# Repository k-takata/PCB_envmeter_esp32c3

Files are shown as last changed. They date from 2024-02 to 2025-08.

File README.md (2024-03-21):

# IoT環境メーター / スマートリモコン

## 概要

ESP32-C3とBoschのBME680を使い、温度、湿度、気圧、二酸化炭素換算値などを測定し、結果を[Ambient](https://ambidata.io/)にアップロードできる環境メーターです。  
表示には0.96inch OLEDを使用し、スイッチで通常表示・詳細表示・簡易表示を切り替えることができます。  
Rev. 2 からは赤外線送受信部を備え、スマートリモコン機能も使うことができます。

Rev. 1 のソフトウェア及び解説記事は「[ESP32-C3とBME680でIoT環境メーターを作る](https://zenn.dev/k_takata/articles/esp32c3-envmeter)」で公開しています。  
Rev. 2 のソフトウェア及び解説記事は以下で公開しています。

* [ESP32-C3とBME680でIoT環境メーター/スマートリモコンを作る (その1)](https://zenn.dev/k_takata/articles/esp32c3-envmeter-rev2-1)
* [ESP32-C3とBME680でIoT環境メーター/スマートリモコンを作る (その2)](https://zenn.dev/k_takata/articles/esp32c3-envmeter-rev2-2)

## 使用したソフトウェア

KiCad 7.0

## 回路図

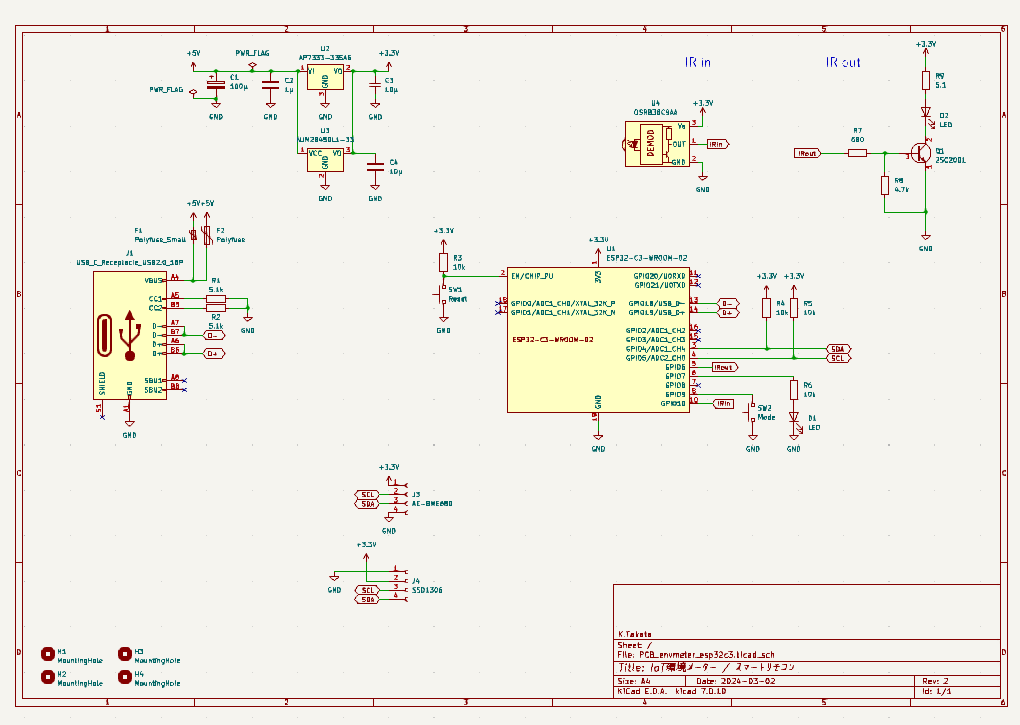
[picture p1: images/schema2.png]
schema rev.2


## 基板パターン図

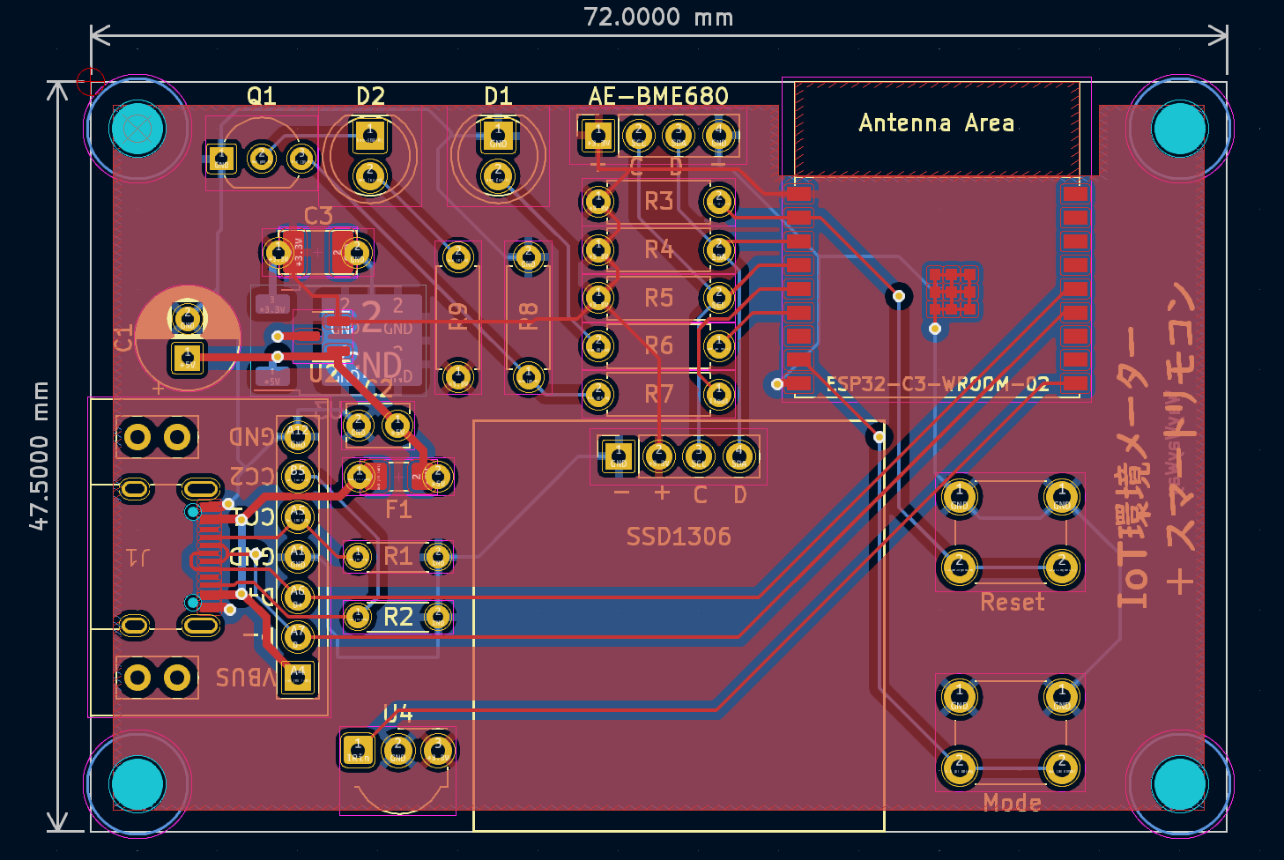
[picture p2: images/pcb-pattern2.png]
PCB pattern rev.2


## 部品表

### IoT環境メーター部分

| Reference |個数|値 | 説明 |
|---|----|---|---|
|C1 | 1|100μF|電解コンデンサー φ6.3[^1] (100 ~ 470μF)|
|C2 | 1|  1μF|[積層セラミックコンデンサー](https://akizukidenshi.com/catalog/g/g115940/)、2.54mmピッチ|
|C3 (\*1) | 1| 10μF|積層セラミックコンデンサー、表面実装 (3225 あるいは 3216 サイズ)|
|C4 (\*1) | 1| 10μF|[積層セラミックコンデンサー](https://akizukidenshi.com/catalog/g/g103095/)、5mmピッチ|
|D1 | 1| |赤色LED φ5|
|F1 (\*2) | 1|  0.5A|[ポリヒューズ](https://akizukidenshi.com/catalog/g/g115300/)、表面実装|
|F2 (\*2) | 1|  1.1A|[ポリヒューズ](https://akizukidenshi.com/catalog/g/g100507/)|
|J1 (\*3) | 1|[5077CR-16-SMC2-BK-TR](https://akizukidenshi.com/catalog/g/g114356/)|USB Type-Cコネクター|
|J2 (\*3) | 1| |[USB Type-CコネクターDIP化キット](https://akizukidenshi.com/catalog/g/g115426/)、[同等品](https://akizukidenshi.com/catalog/g/g113080/)でも可|
|J3 | 1| |[細ピンソケット](https://akizukidenshi.com/catalog/g/g110073/) 1x4 (あるいは[1列ICソケット](https://akizukidenshi.com/catalog/g/g103470/))|
|J4 | 1| |[ピンソケット](https://akizukidenshi.com/catalog/g/g105779/) 1x4 (あるいは[ロープロファイルピンソケット](https://akizukidenshi.com/catalog/g/g100661/))|
|(J3) | 1|[AE-BME680](https://akizukidenshi.com/catalog/g/g114469/)|総合環境センサー|
|(J4) | 1| |[0.96インチ 128×64ドット OLED](https://akizukidenshi.com/catalog/g/g112031/)、SSD1306搭載|
|R1, R2 | 2|5.1kΩ|緑茶赤金、小型|
|R3, R4, R5, R6 | 4| 10kΩ|茶黒橙金|
|SW1 | 1|Reset |[タクトスイッチ(赤)](https://akizukidenshi.com/catalog/g/g103646/)|
|SW2 | 1|Mode  |[タクトスイッチ(黒)](https://akizukidenshi.com/catalog/g/g103647/)|
|U1 | 1|[ESP32-C3-WROOM-02-N4](https://akizukidenshi.com/catalog/g/g117493/)|Wi-Fi モジュール|
|U2 (\*4) | 1|[AP7333-33SAG](https://akizukidenshi.com/catalog/g/g111360/)|低損失三端子レギュレーター 3.3V 300mA|
|U3 (\*4) | 1|[NJM2845DL1-33](https://akizukidenshi.com/catalog/g/g111299/)|低損失三端子レギュレーター 3.3V 800mA|

[^1]: このサイズならば、まっすぐ足が奥まで挿せる。

注:
* (\*1) C3, C4はどちらかを選択します。基板上にはC3の表示のみあります。表面実装の半田付けが難しい場合はC4を選択してください。
* (\*2) F1, F2はどちらかを選択します。基板上にはF1の表示のみあります。F1がお勧めですが、表面実装の半田付けが難しい場合はF2でも可です。
* (\*3) J1, J2はどちらかを選択します。基板上にはJ1の表示のみあります。表面実装の半田付けが難しい場合はJ2を選択してください。
* (\*4) U2, U3はどちらかを選択します。U2の方が安価ですが300mAしか使えないため、Wi-Fiをフルパワーで使いたい場合は、U3の方がお勧めです。
* AE-BME680を取り外す予定がなければ、ピンソケット(J3)を使わず直接接続してもかまいません。
* OLEDを取り外す予定がなければ、ピンソケット(J4)を使わず直接接続してもかまいません。

### 赤外線受信部

| Reference |個数|値 | 説明 |
|---|----|---|---|
|U4 | 1|[OSRB38C9AA](https://akizukidenshi.com/catalog/g/g104659/)|赤外線リモコン受信モジュール|

注: 赤外線リモコン受信機能を使わない場合は組み立て不要です。

### 赤外線送信部

| Reference |個数|値 | 説明 |
|---|----|---|---|
|D2 | 1|[OSI5LA5113A](https://akizukidenshi.com/catalog/g/g112612/)|赤外線LED φ5|
|Q1 | 1|[2SC2001](https://akizukidenshi.com/catalog/g/g113828/)||
|R7 | 1| 680Ω|青灰茶金|
|R8 | 1|4.7kΩ|黄紫赤金|
|R9 | 1| 5.1Ω|緑茶金金、1/2W 小型|

注: 赤外線リモコン送信機能を使わない場合は組み立て不要です。

## 使い方

### Rev. 1

「[ESP32-C3とBME680でIoT環境メーターを作る](https://zenn.dev/k_takata/articles/esp32c3-envmeter)」を参照してください。

### Rev. 2

以下の記事を参照してください。

* [ESP32-C3とBME680でIoT環境メーター/スマートリモコンを作る (その1)](https://zenn.dev/k_takata/articles/esp32c3-envmeter-rev2-1)
* [ESP32-C3とBME680でIoT環境メーター/スマートリモコンを作る (その2)](https://zenn.dev/k_takata/articles/esp32c3-envmeter-rev2-2)

## 完成品

### Rev. 1

通常表示<br>
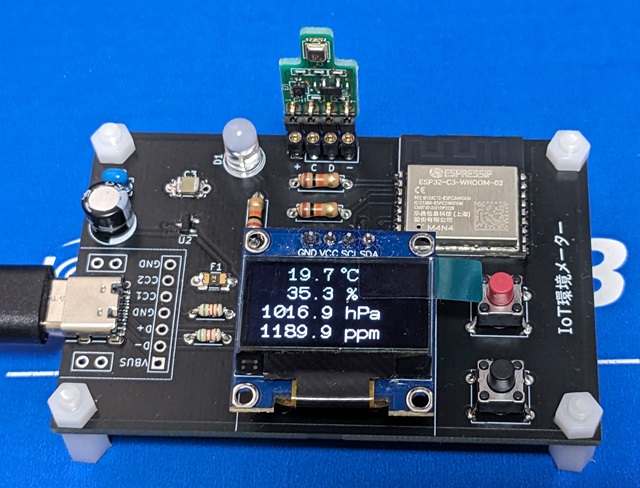
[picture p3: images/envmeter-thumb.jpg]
完成品、通常表示


詳細表示<br>
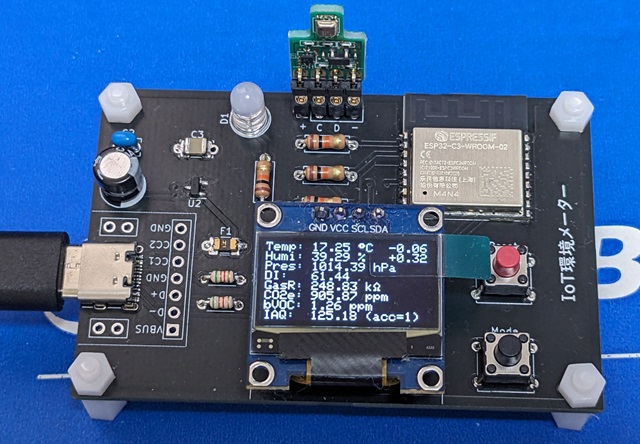
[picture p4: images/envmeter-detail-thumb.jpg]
完成品、詳細表示


簡易表示<br>
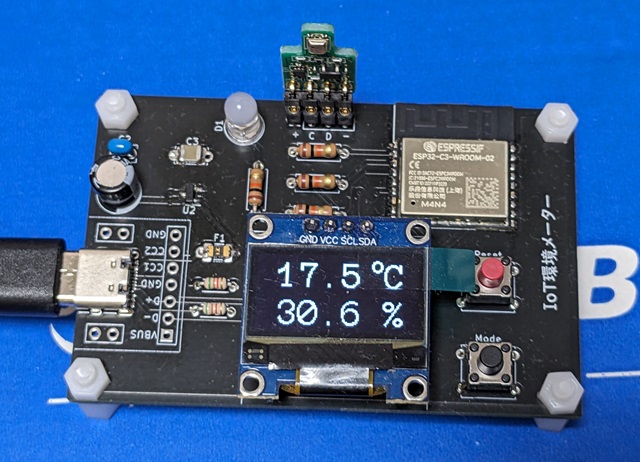
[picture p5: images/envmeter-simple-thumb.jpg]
完成品、簡易表示


### Rev. 2

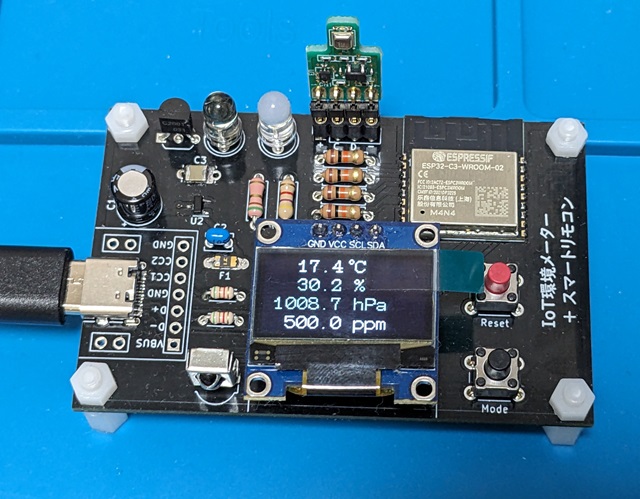
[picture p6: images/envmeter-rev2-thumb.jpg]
Rev.2 完成品、通常表示


## License

CC0

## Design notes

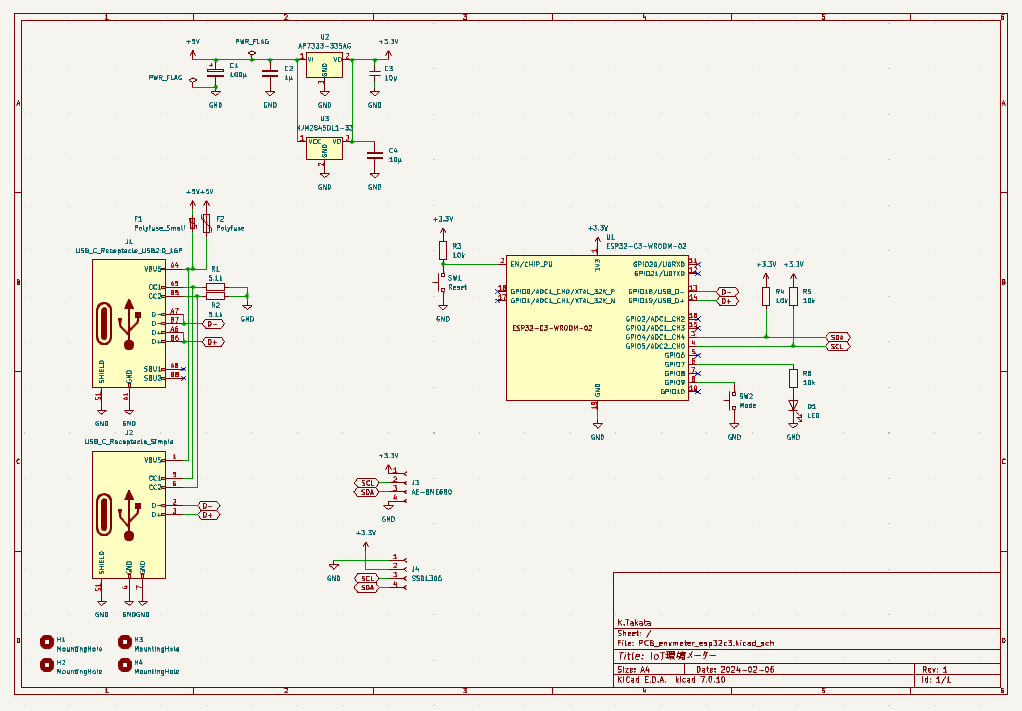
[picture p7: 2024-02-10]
images/schema.png

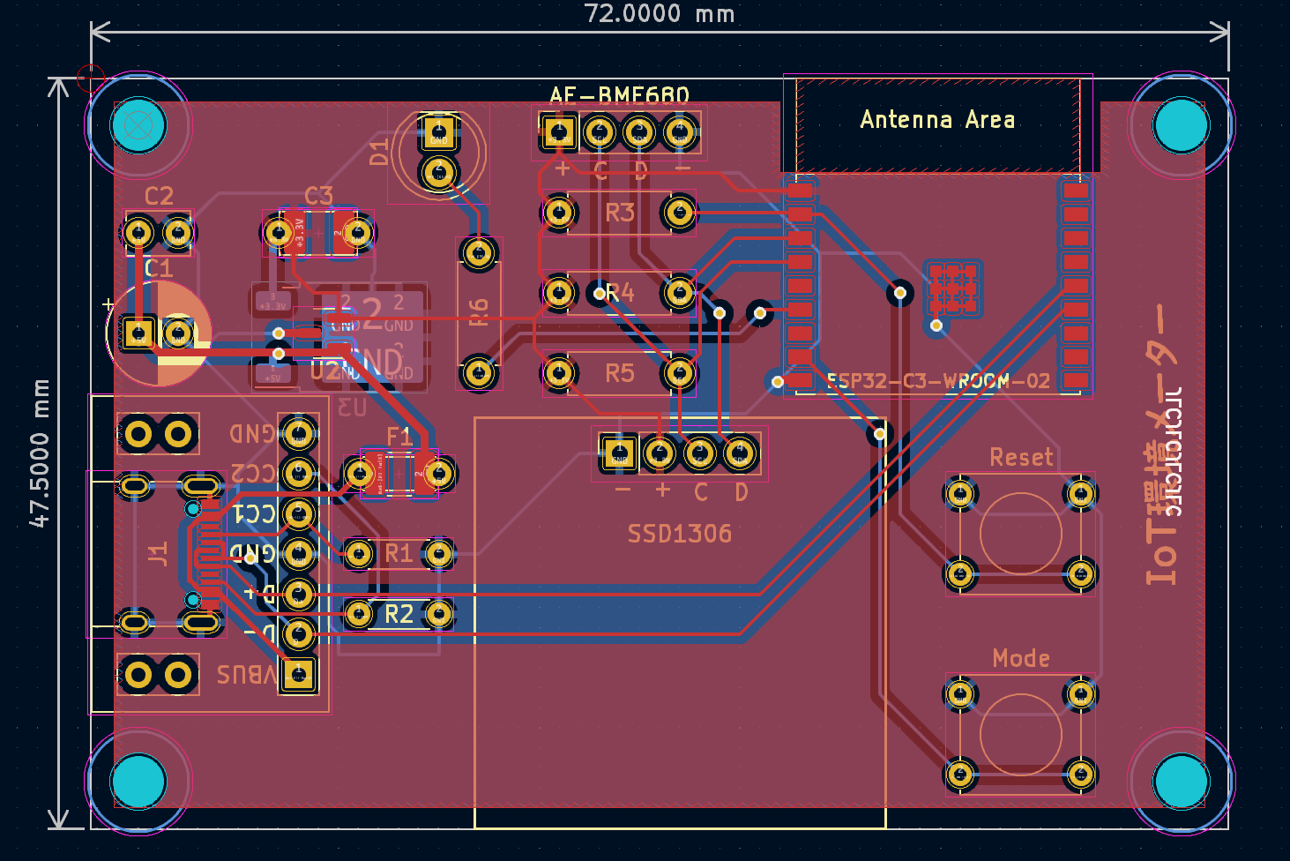
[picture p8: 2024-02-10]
images/pcb-pattern.png

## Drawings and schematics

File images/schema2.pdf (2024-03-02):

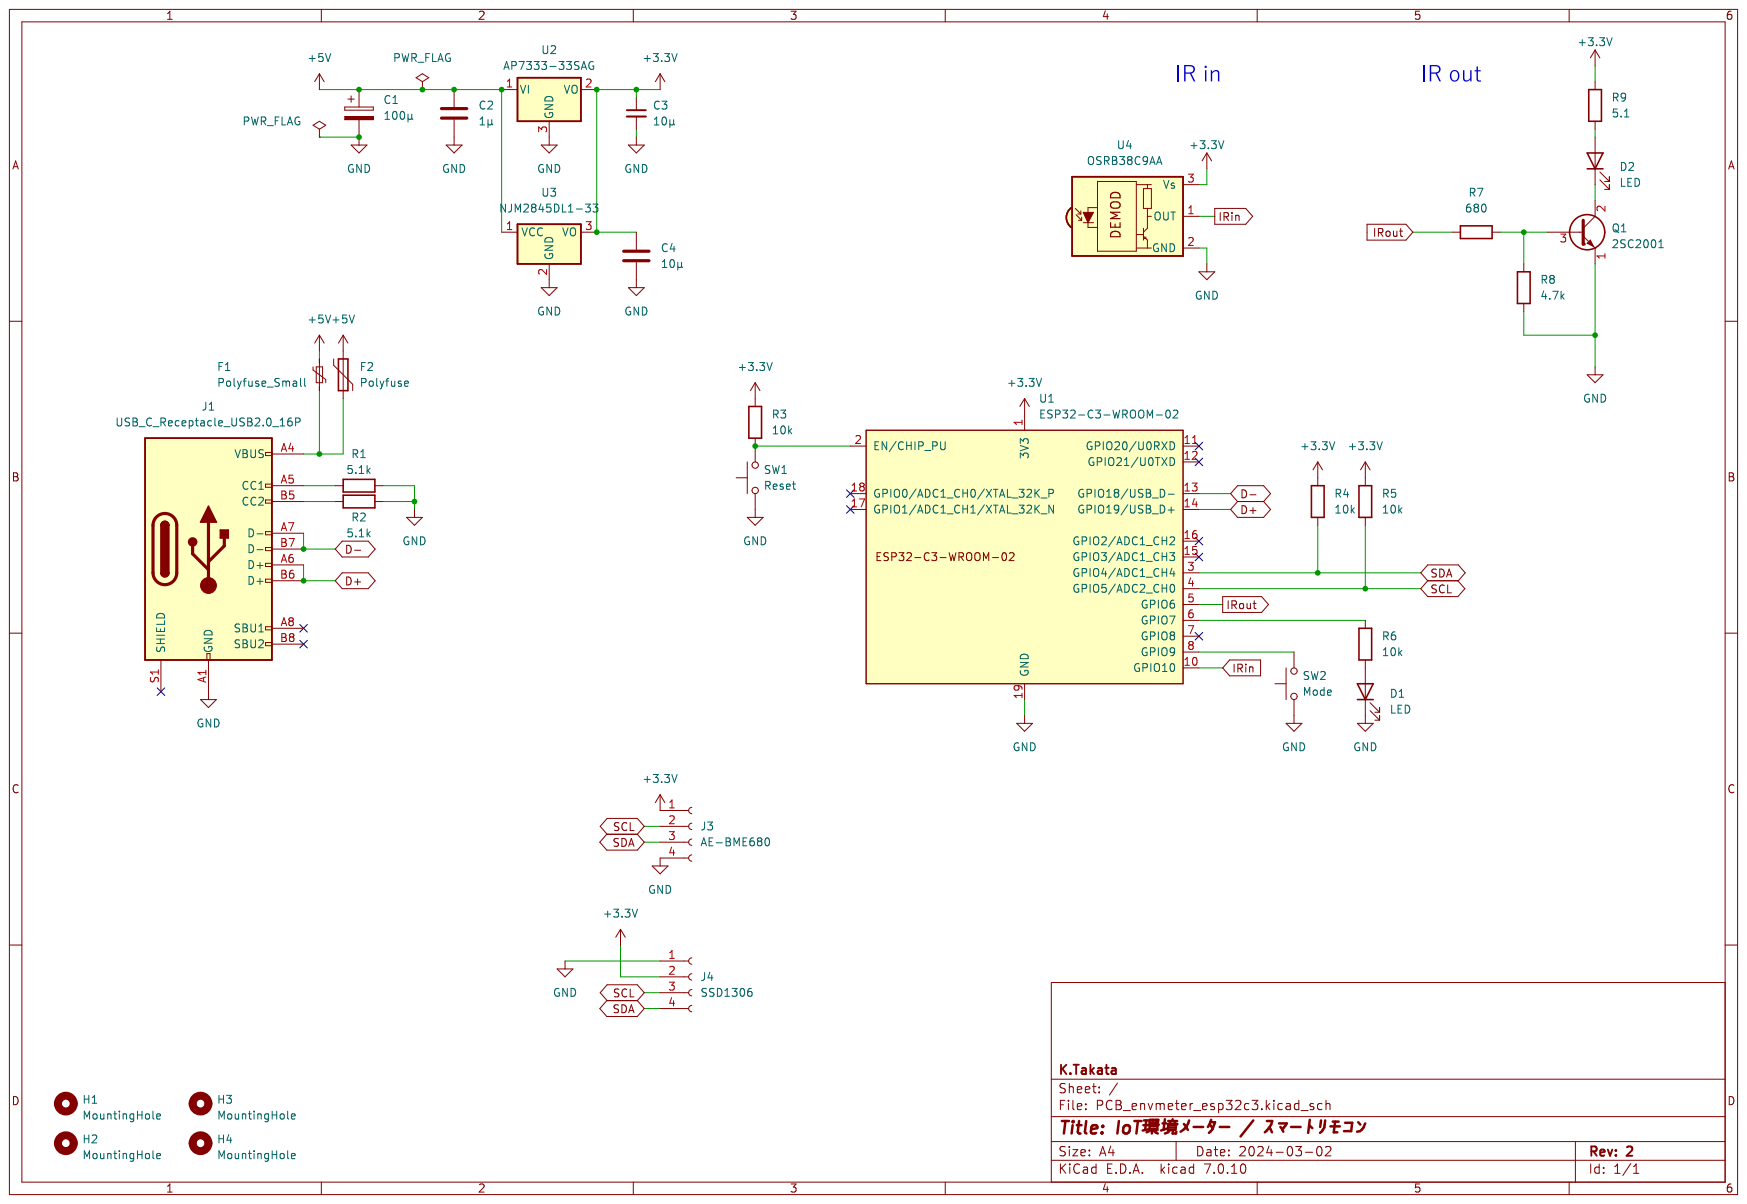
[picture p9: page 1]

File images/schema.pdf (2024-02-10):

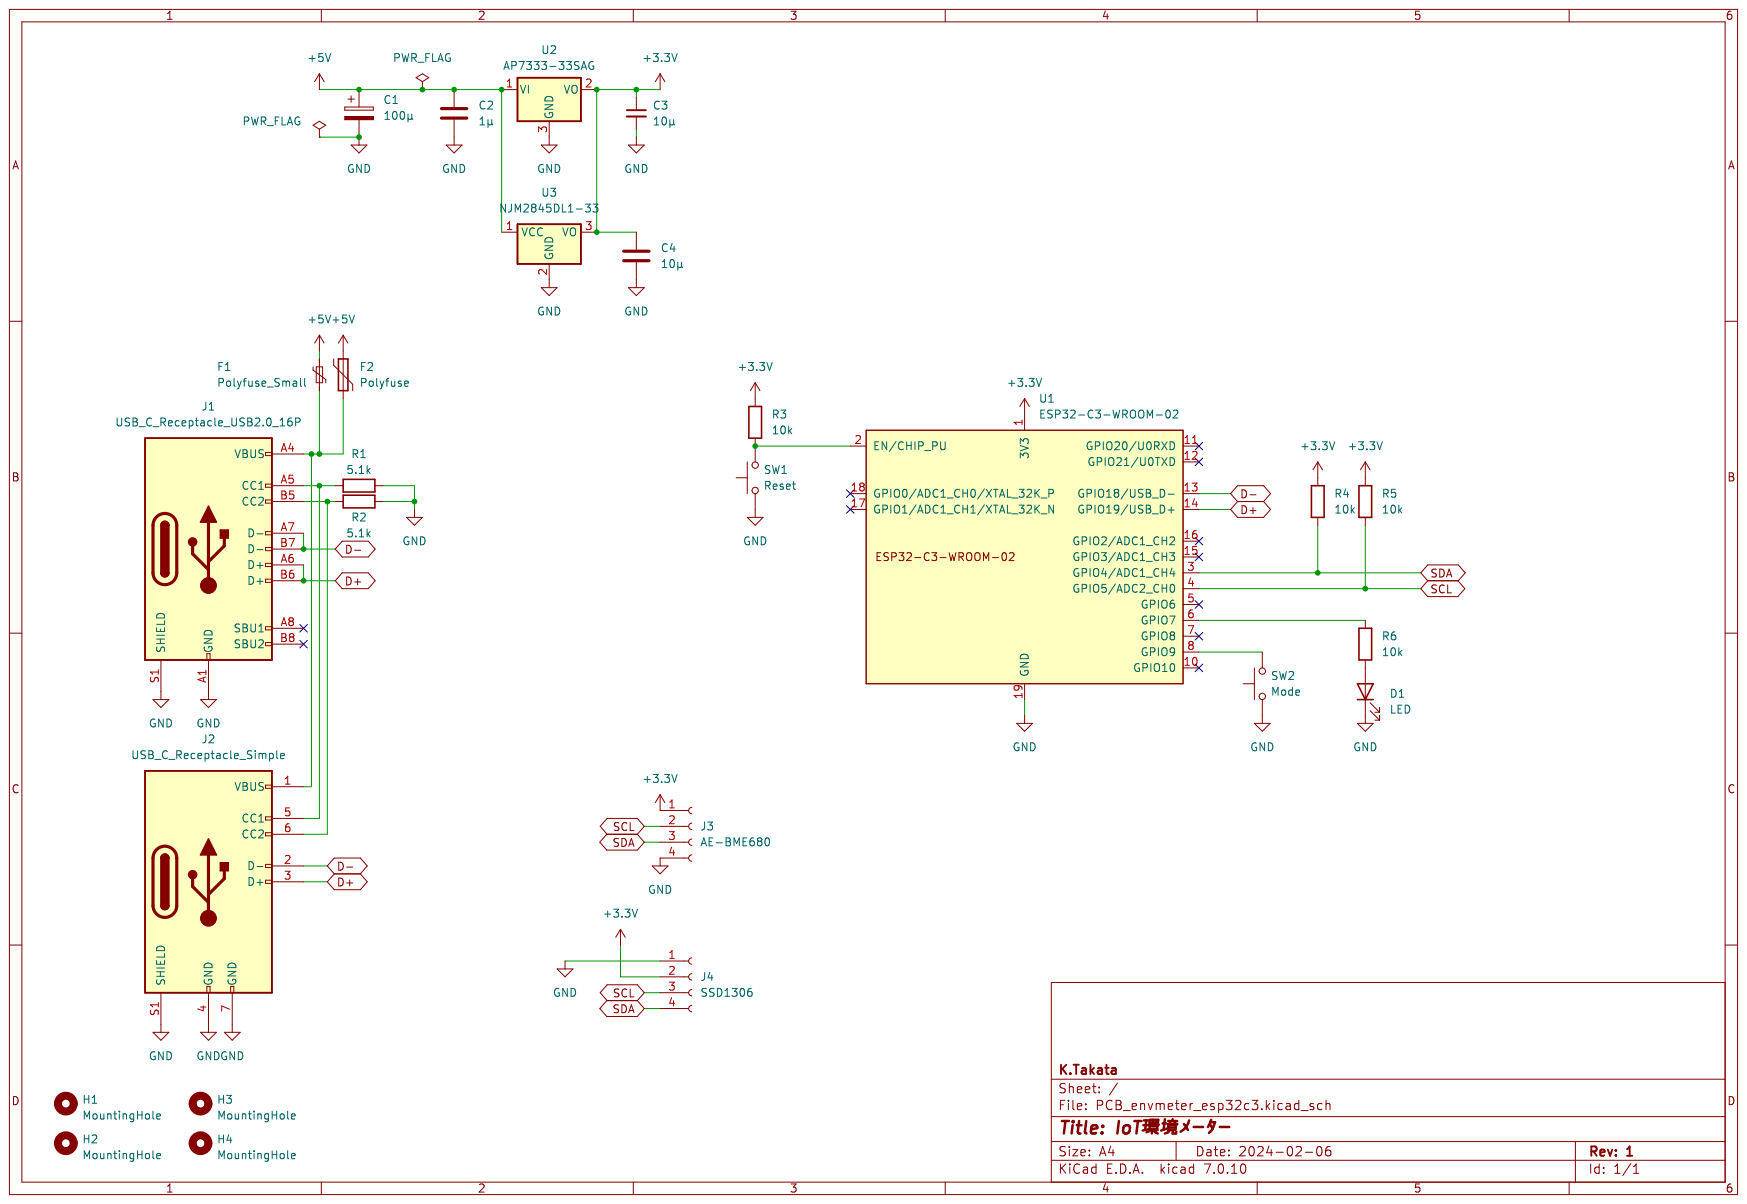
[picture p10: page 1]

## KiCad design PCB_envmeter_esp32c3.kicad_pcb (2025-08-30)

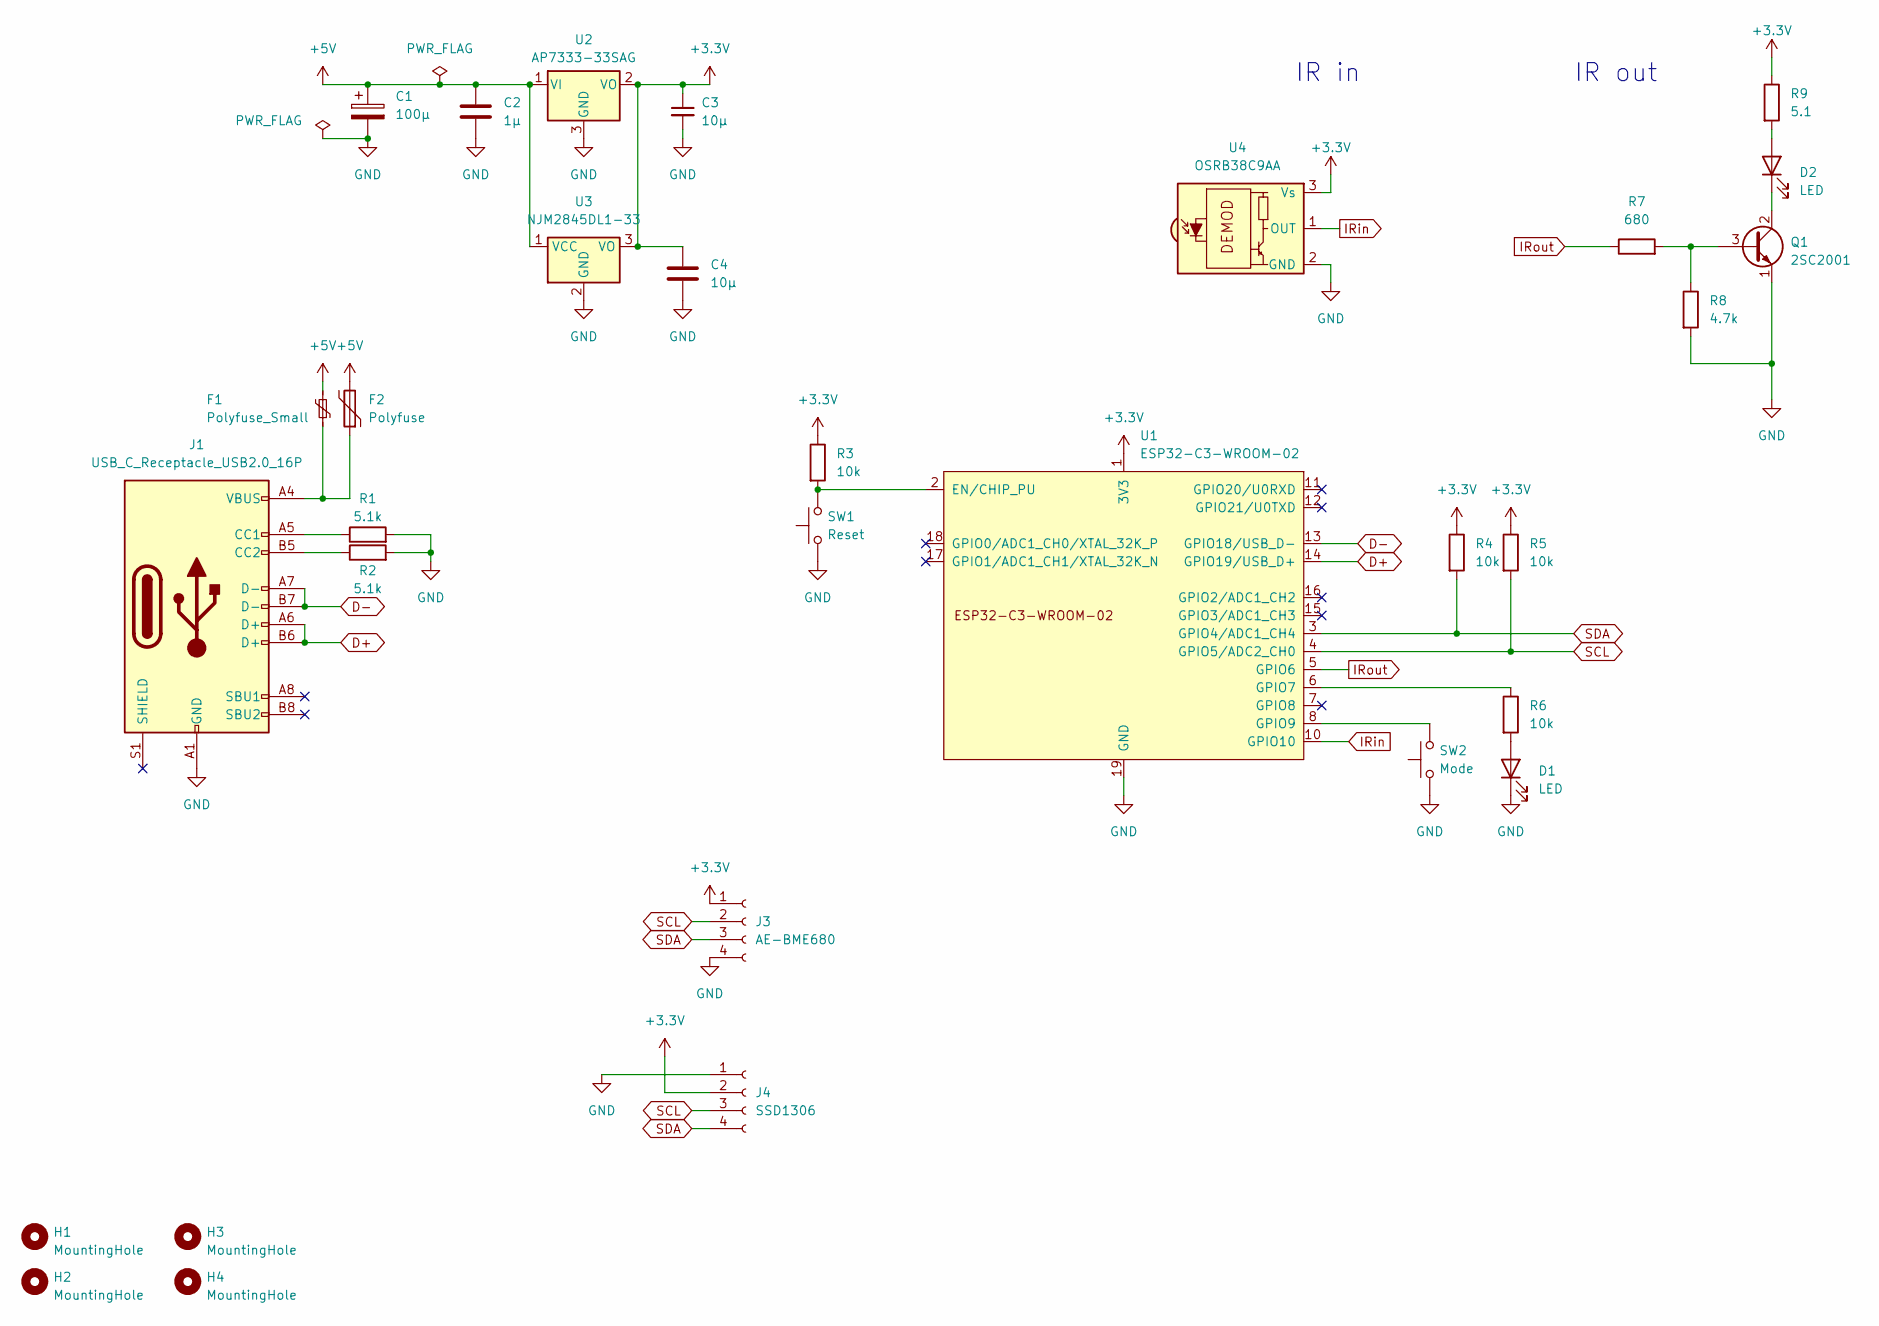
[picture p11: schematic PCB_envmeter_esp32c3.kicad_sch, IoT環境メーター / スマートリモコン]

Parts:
C1: 100μ; CP_Radial_D6.3mm_P2.50mm
C2: 1μ; C_Disc_D3.8mm_W2.6mm_P2.50mm
C3: 10μ; C_1210_3225Metric_Pad1.33x2.70mm_HandSolder
C4: 10μ; C_Disc_D4.7mm_W2.5mm_P5.00mm
D1: LED; LED_D5.0mm
D2: LED; LED_D5.0mm_IRGrey
F1: Polyfuse_Small; Fuse_1206_3216Metric_Pad1.42x1.75mm_HandSolder
F2: Polyfuse; C_Disc_D4.3mm_W1.9mm_P5.00mm
H1, H2, H3, H4: MountingHole; MountingHole_3.2mm_M3
J1: USB_C_Receptacle_USB2.0_16P; Connector_USB_C_simple_combo
J3: AE-BME680; PinSocket_1x04_P2.54mm_Vertical
J4: SSD1306; PinSocket_1x04_P2.54mm_Vertical
Q1: 2SC2001; TO-92_Inline_Wide
R1, R2: 5.1k; R_Axial_DIN0204_L3.6mm_D1.6mm_P5.08mm_Horizontal
R3, R4, R5, R6: 10k; R_Axial_DIN0207_L6.3mm_D2.5mm_P7.62mm_Horizontal
R7: 680; R_Axial_DIN0207_L6.3mm_D2.5mm_P7.62mm_Horizontal
R8: 4.7k; R_Axial_DIN0207_L6.3mm_D2.5mm_P7.62mm_Horizontal
R9: 5.1; R_Axial_DIN0207_L6.3mm_D2.5mm_P7.62mm_Horizontal
SW1: Reset; SW_PUSH_6mm
SW2: Mode; SW_PUSH_6mm
U1: ESP32-C3-WROOM-02
U2: AP7333-33SAG; SOT-23
U3: NJM2845DL1-33; TO-252-2
U4: OSRB38C9AA; Vishay_MOLD-3Pin

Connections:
+3.3V: C3.1, C4.1, J3.1, J4.2, R3.1, R4.1, R5.1, R9.1, U1.1 (3V3), U2.2 (VO), U3.3 (VO), U4.3 (Vs)
+5V: C1.1, C2.1, F1.2, F2.2, U2.1 (VI), U3.1 (VCC)
D+: J1.A6 (D+), J1.B6 (D+), U1.14 (GPIO19/USB_D+)
D-: J1.A7 (D-), J1.B7 (D-), U1.13 (GPIO18/USB_D-)
GND: C1.2, C2.2, C3.2, C4.2, D1.1 (K), J1.A1 (GND), J1.A12 (GND), J1.B1 (GND), J1.B12 (GND), J3.4, J4.1, Q1.1 (E), R1.2, R2.2, R8.2, SW1.1, SW2.1, U1.9 (GND), U1.19 (GND), U2.3 (GND), U3.2 (GND), U4.2 (GND)
IRin: U1.10 (GPIO10), U4.1 (OUT)
IRout: R7.1, U1.5 (GPIO6)
unnamed: D1.2 (A), R6.2
unnamed: D2.2 (A), R9.2
unnamed: D2.1 (K), Q1.2 (C)
unnamed: F1.1, F2.1, J1.A4 (VBUS), J1.A9 (VBUS), J1.B4 (VBUS), J1.B9 (VBUS)
unnamed: J1.A5 (CC1), R1.1
unnamed: J1.B5 (CC2), R2.1
unnamed: Q1.3 (B), R7.2, R8.1
unnamed: R3.2, SW1.2, U1.2 (EN/CHIP_PU)
unnamed: R6.1, U1.6 (GPIO7)
unnamed: SW2.2, U1.8 (GPIO9)
SCL: J3.2, J4.3, R5.2, U1.4 (GPIO5/ADC2_CH0)
SDA: J3.3, J4.4, R4.2, U1.3 (GPIO4/ADC1_CH4)

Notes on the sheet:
IR out
IR in

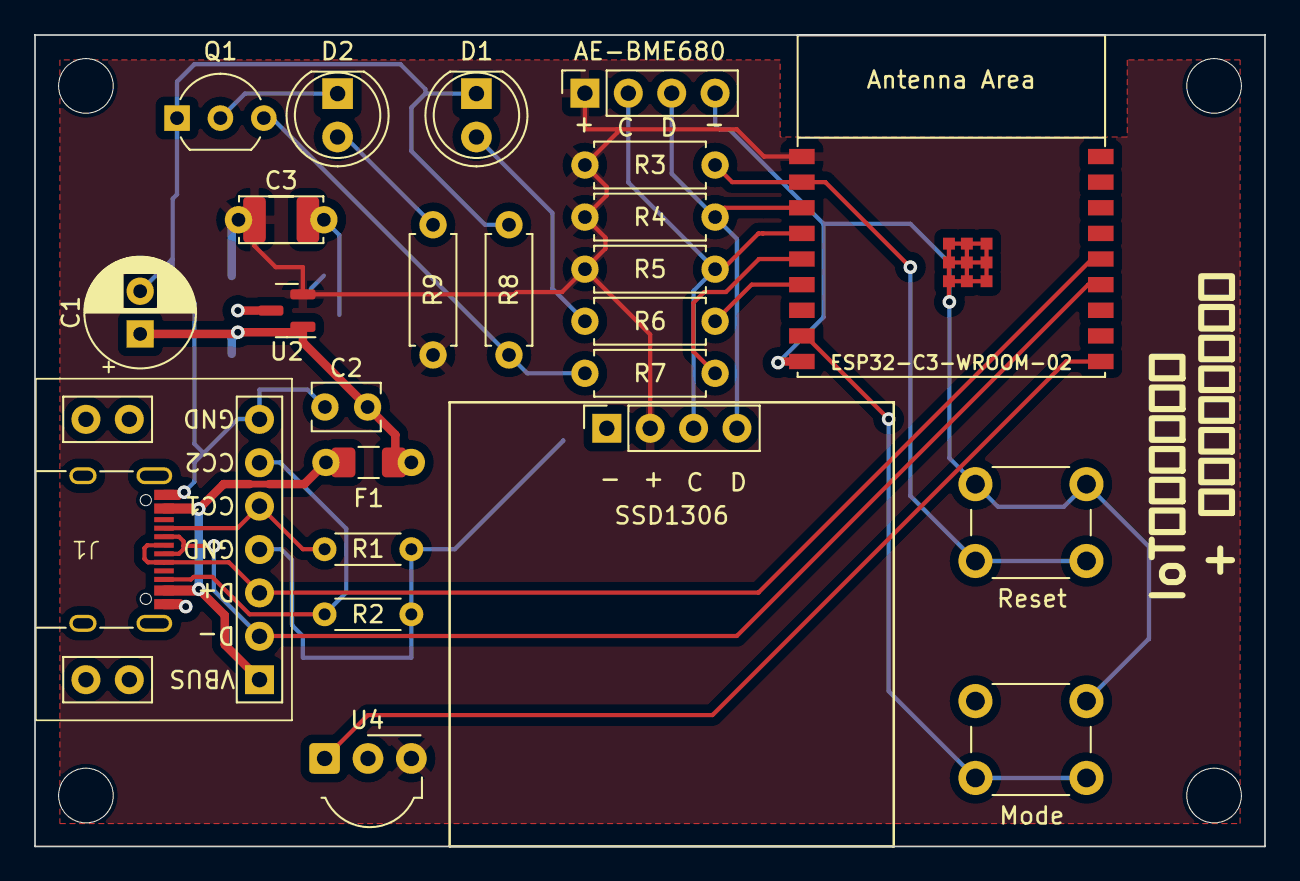
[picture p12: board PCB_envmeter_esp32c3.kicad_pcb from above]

Board: 2 copper layers, 72.0 x 47.5 mm, 31 parts (1 on the bottom side), 19 nets.

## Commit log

2024-02-10 Add title
    [PCB_envmeter_esp32c.kicad_pcb]
2024-02-10 Rename the project files
    [PCB_envmeter_esp32c3.kicad_pcb, PCB_envmeter_esp32c3.kicad_sch]
2024-02-10 Initial version
    [PCB_envmeter_esp32c.kicad_pcb, PCB_envmeter_esp32c.kicad_sch]
2024-02-10 Adjust schema layout
    [PCB_envmeter_esp32c.kicad_sch]
2024-02-10 Update
    Values are changed after Garber files are generated.
    [PCB_envmeter_esp32c.kicad_pcb]
2024-02-11 doc: Change J3
    J3 を細ピンソケットに変更。
2024-02-17 Disconnect shield to GND
    [PCB_envmeter_esp32c3.kicad_pcb, PCB_envmeter_esp32c3.kicad_sch]
2024-02-17 Adjust capacitors position
    [PCB_envmeter_esp32c3.kicad_pcb]
2024-02-17 Revise wiring around USB connector
    [PCB_envmeter_esp32c3.kicad_pcb]
2024-02-17 Change footprint of SW1,2
    [PCB_envmeter_esp32c3.kicad_pcb, PCB_envmeter_esp32c3.kicad_sch]
2024-02-18 Change footprint
    [PCB_envmeter_esp32c3.kicad_pcb, PCB_envmeter_esp32c3.kicad_sch]
2024-02-24 完成品の写真を追加
2024-02-25 詳細表示の写真を追加
2024-02-25 Update F1 footprint
    [PCB_envmeter_esp32c3.kicad_pcb, PCB_envmeter_esp32c3.kicad_sch]
2024-03-01 Rev. 2
    * スマートリモコン機能追加
    - 赤外線送信部
    - 赤外線受信部
    * AE-BME680とSSD1306のパッド穴サイズを1.0mmから0.9mmに変更
    * JLCJLCJLCJLC を WayWayWay に変更
    [PCB_envmeter_esp32c3.kicad_pcb, PCB_envmeter_esp32c3.kicad_sch]
2024-03-01 Ignore pcbway_production
2024-03-01 Replace OSRB38C9AA symbol
    [PCB_envmeter_esp32c3.kicad_pcb, PCB_envmeter_esp32c3.kicad_sch]
2024-03-09 Add 3D model for USB connector
    [PCB_envmeter_esp32c3.kicad_pcb]
2025-06-30 Update font name
    [PCB_envmeter_esp32c3.kicad_pcb]
2025-08-30 Adjust OLED position
    [PCB_envmeter_esp32c3.kicad_pcb]
